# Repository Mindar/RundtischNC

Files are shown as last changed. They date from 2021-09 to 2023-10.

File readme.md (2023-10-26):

# Rundtisch NC
Rundtisch NC is a numerical control for indexing heads. It allows you to set a number of divisons using a rotary encoder and then drives the right distance on the push of a button.

*For international visitors: Unfortunately this repository is mostly in german. A notable exception to this is the firmware. In the future there might be a english version of the documentation, but for now there isn't one 😪*

[User manual / Bedienungsanleitung 🇩🇪 (.pdf)](./doc/bedienungsanleitung.pdf)

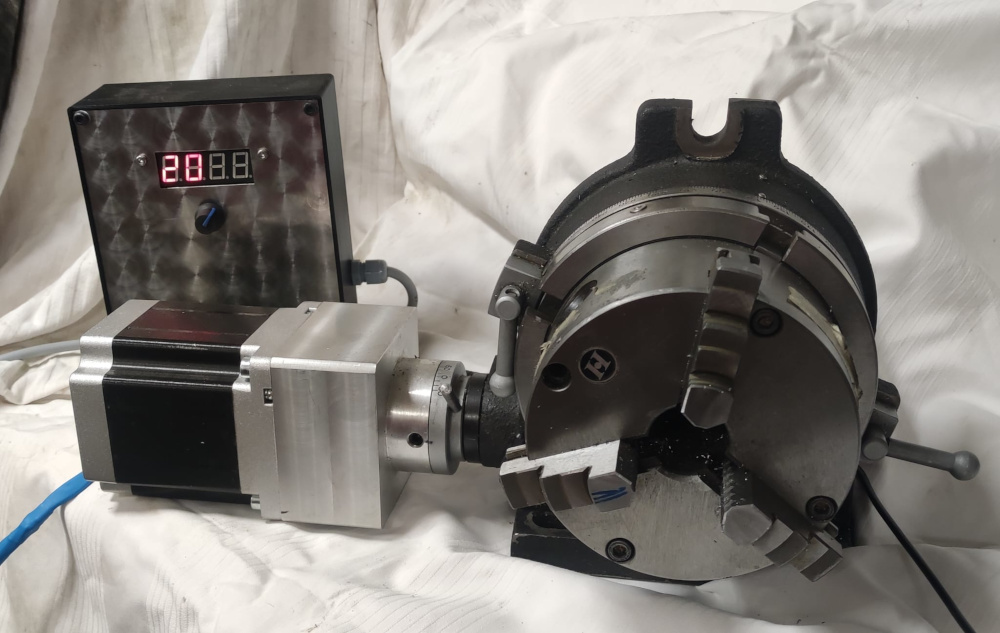
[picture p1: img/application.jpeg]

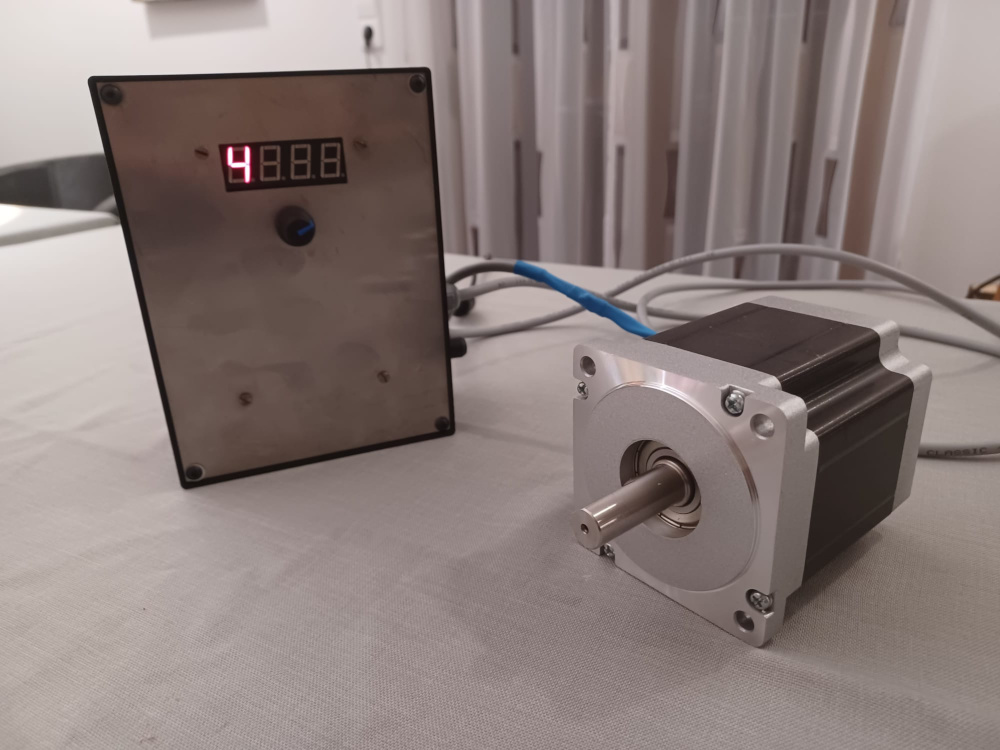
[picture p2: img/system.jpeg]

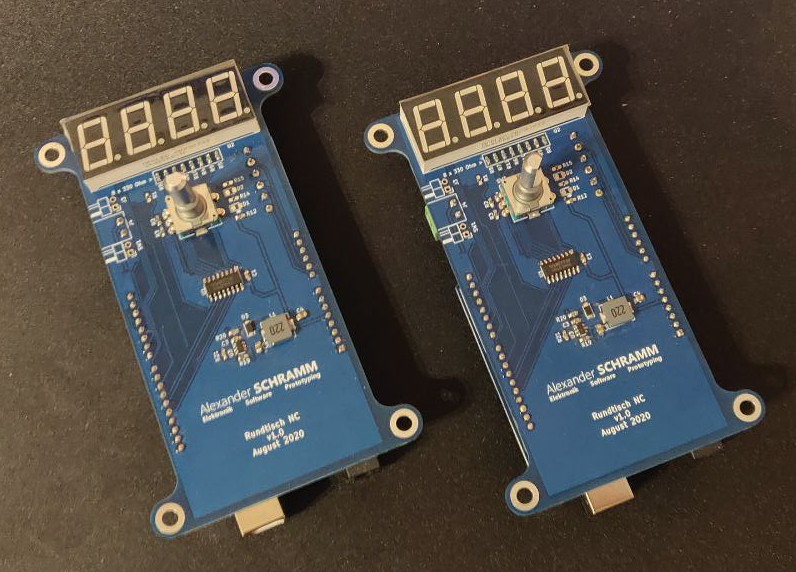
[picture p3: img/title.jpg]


## License
- Firmware: MIT
- Documentation, PCB layout, schematic, images: Creative Commons CC-BY (or MIT)

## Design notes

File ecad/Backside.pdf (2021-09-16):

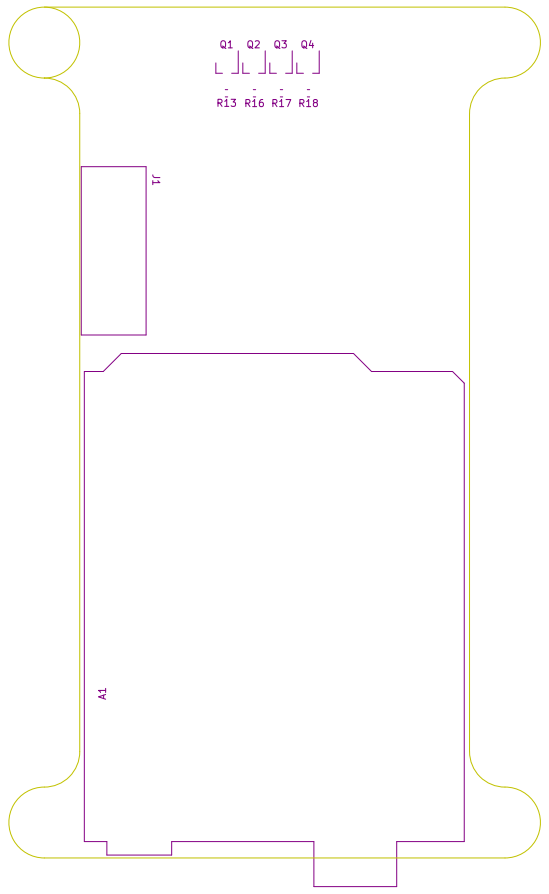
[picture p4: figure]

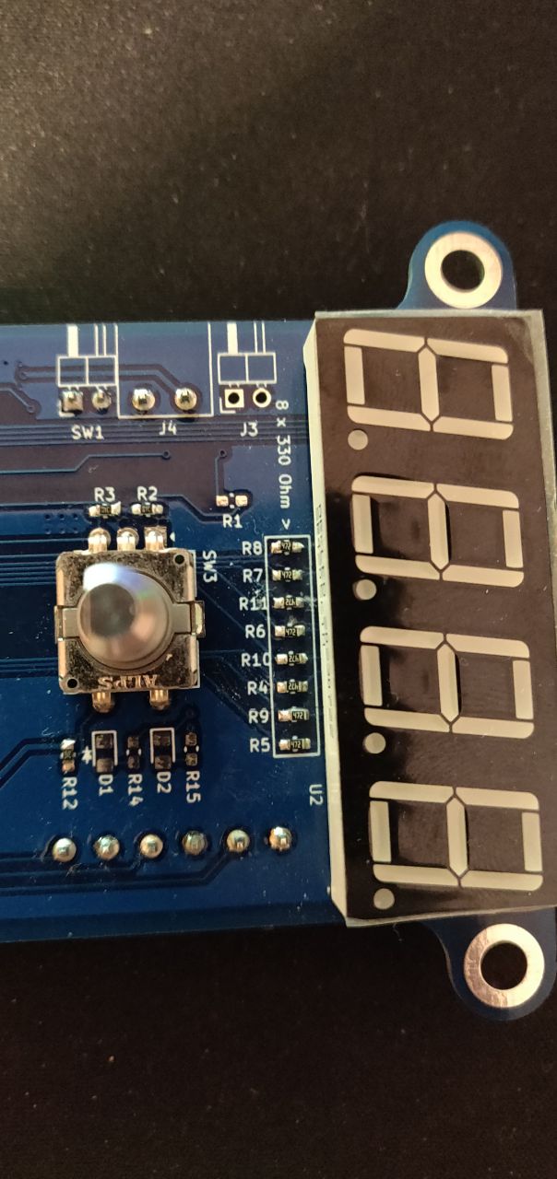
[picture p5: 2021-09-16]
img/display-widerstände.jpg

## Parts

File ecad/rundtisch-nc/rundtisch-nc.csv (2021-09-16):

Source: | /home/alex/Dokumente/firma/produkte/rundtisch-nc/ecad/rundtisch-nc/rundtisch-nc.kicad_sch
Date: | Sa 03 Okt 2020 22:12:33 CEST
Tool: | Eeschema (5.99.0-3702-g8080647d3-dirty)
Generator: | /usr/local/share/kicad/plugins/bom_csv_grouped_by_value_with_fp.py
Component Count: | 44
Ref | Qnty | Value | Cmp name | Footprint | Description | Vendor
A1, | 1 | Arduino_UNO_R3 | Arduino_UNO_R3 | Module:Arduino_UNO_R3 | Arduino UNO Microcontroller Module, release 3
C1, C3, | 2 | 100nF | C | Capacitor_SMD:C_0603_1608Metric_Pad1.05x0.95mm_HandSolder | Unpolarized capacitor
C2, C4, | 2 | 10uF | C | Capacitor_SMD:C_0805_2012Metric_Pad1.15x1.40mm_HandSolder | Unpolarized capacitor
D1, | 1 | Mode 1 LED | LED | LED_SMD:LED_0805_2012Metric_Pad1.15x1.40mm_HandSolder | Light emitting diode
D2, | 1 | Mode 2 LED | LED | LED_SMD:LED_0805_2012Metric_Pad1.15x1.40mm_HandSolder | Light emitting diode
D3, | 1 | DSK14 | D_Schottky | Diode_SMD:D_SOD-123 | Schottky diode
J1, | 1 | Motor Connector | Conn_01x06 | sonstige:WJ15EDGRC-3.81-6P | Generic connector, single row, 01x06, script generated (kicad-library-utils/schlib/autogen/connector/)
J2, | 1 | Conn_01x02_Male | Conn_01x02_Male |  | Generic connector, single row, 01x02, script generated (kicad-library-utils/schlib/autogen/connector/)
J3, | 1 | Feed Button Connector | Conn_01x02_Female | Connector_PinHeader_2.54mm:PinHeader_1x02_P2.54mm_Horizontal | Generic connector, single row, 01x02, script generated (kicad-library-utils/schlib/autogen/connector/)
J4, | 1 | Power In | Conn_01x02 | sonstige:WJ15EDGRC-3.81-2P | Generic connector, single row, 01x02, script generated (kicad-library-utils/schlib/autogen/connector/)
L1, | 1 | FXC0630-220M | L | sonstige:FXC0630-220M | Inductor
Q1, Q2, Q3, Q4, | 4 | AO3402 | Q_NMOS_GDS | Package_TO_SOT_SMD:SOT-23_Handsoldering | N-MOSFET transistor, gate/drain/source
R1, R2, R3, R12, R13, R16, R17, R18, R19, | 9 | 10K | R | Resistor_SMD:R_0603_1608Metric_Pad1.05x0.95mm_HandSolder | Resistor
R4, R5, R6, R7, R8, R9, R10, R11, | 8 | 330R | R | Resistor_SMD:R_0603_1608Metric_Pad1.05x0.95mm_HandSolder | Resistor
R14, R15, | 2 | 470R | R | Resistor_SMD:R_0603_1608Metric_Pad1.05x0.95mm_HandSolder | Resistor
R20, | 1 | 50K | R | Resistor_SMD:R_0603_1608Metric_Pad1.05x0.95mm_HandSolder | Resistor
R21, | 1 | 9.53K | R | Resistor_SMD:R_0603_1608Metric_Pad1.05x0.95mm_HandSolder | Resistor
SW1, | 1 | Reset Button | SW_Push | Connector_PinHeader_2.54mm:PinHeader_1x02_P2.54mm_Horizontal | Push button switch, generic, two pins
SW2, | 1 | Feed Advance Button | SW_Push |  | Push button switch, generic, two pins
SW3, | 1 | Rotary Encoder | Rotary_Encoder_Switch | Rotary_Encoder:RotaryEncoder_Alps_EC11E-Switch_Vertical_H20mm | Rotary encoder, dual channel, incremental quadrate outputs, with switch
U1, | 1 | 74HC595 | 74HC595 | Package_SO:SOIC-16_3.9x9.9mm_P1.27mm | 8-bit serial in/out Shift Register 3-State Outputs
U2, | 1 | SR420561N | CC56-12YWA | sonstige:SR420561N | 4 digit 7 segment yellow LED, common cathode
U3, | 1 | AOZ1282CI | AOZ1282CI | Package_TO_SOT_SMD:SOT-23-6 | 1.2 A Simple Buck Regulator, 4.5-36V input, 450kHz

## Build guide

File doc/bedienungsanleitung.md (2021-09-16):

# Bedienungsanleitung

## Verkabelung
Es müssen nur die beiden grünen Steckverbinder verkabelt werden. An den 6-poligen Steckverbinder wird der Motortreiber angeschlossen. An den 2-poligen Steckverbinder wird die Stromversorgung angeschlossen.

### Motortreiber
Der Schrittmotortreiber muss auf 400 Schritte pro Umdrehung eingestellt werden. Falls das nicht möglich ist, oder eine andere Schritteinstellung verwendet werden soll, siehe unten Abschnitt im "Firmware Einstellungen".

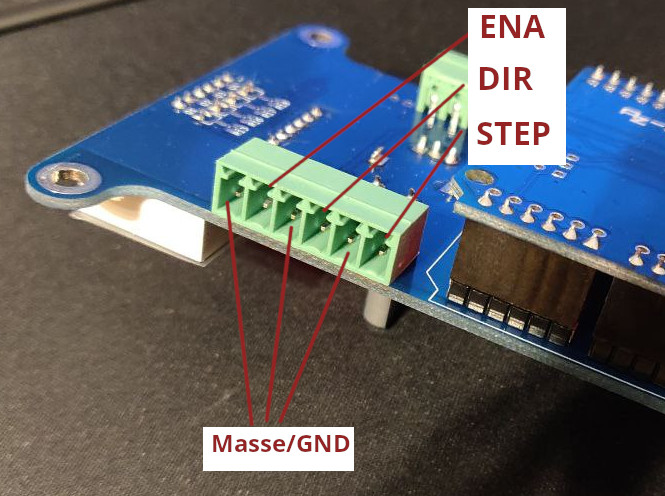
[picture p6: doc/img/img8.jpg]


Pin 1 des 6-poligen Steckverbinders J1 ist näher am Arduino, Pin 6 ist neben dem Schriftzug "J1". Die Pins müssen wie folgt verkabelt werden:

<table>
<thead>
	<tr>
		<th>Pin</th>
		<th>Bezeichnung</th>
		<th>Zugehöriger Pin am Motortreiber</th>
	</tr>
</thead>
<tbody>
	<tr>
		<td>J1.1</td>
		<td>STEP</td>
		<td>Schrittimpulseingang (meistens mit PUL, PULSE, STEP oder STP beschriftet)</td>
	</tr>
	<tr>
		<td>J1.2</td>
		<td>GND</td>
		<td>Masse für Schrittimpulseingang (meistens auch mit STEP- oder GND beschriftet)</td>
	</tr>
	<tr>
		<td>J1.3</td>
		<td>DIR</td>
		<td>Richtungseingang (meistens mit DIR oder DIR+ beschriftet)</td>
	</tr>
	<tr>
		<td>J1.4</td>
		<td>GND</td>
		<td>Masse für Richtungseingang (meistens mit DIR- oder GND beschriftet)</td>
	</tr>
	<tr>
		<td>J1.5</td>
		<td>STEP</td>
		<td>Enable-Eingang (meistens auch mit ENA oder ENA+ beschriftet)</td>
	</tr>
	<tr>
		<td>J1.6</td>
		<td>GND</td>
		<td>Masse für Enable (meistens mit ENA- oder GND beschriftet)</td>
	</tr>
</tbody>
</table>

### Versorgungsspannung
Am 2-poligen Steckverbinder J4 wird die Versorgungsspannung angeschlossen. Die Versorgungsspannung darf maximal 24V (Gleichspannung) betragen. Getestet wird mit 12V.

Die Pins von J4 (Achtung: Beschriftung ist auf gegenüberliegender Seite) sind gleich nummeriert wie die von J1, d.h. "unten" (also näher am Arduino) ist Pin 1.

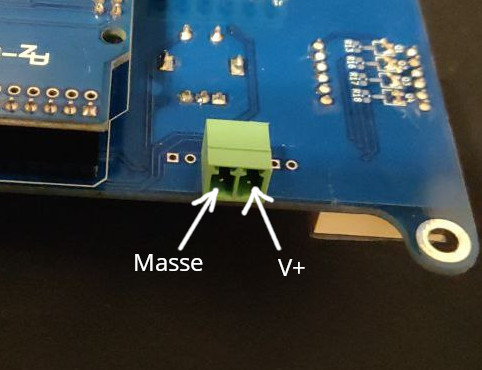
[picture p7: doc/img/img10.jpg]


<table>
<thead>
	<tr>
		<th>Pin</th>
		<th>Bezeichnung</th>
	</tr>
</thead>
<tbody>
	<tr>
		<td>J4.1</td>
		<td>GND</td>
	</tr>
	<tr>
		<td>J4.2</td>
		<td>V+ (kann zwischen )</td>
	</tr>
</tbody>
</table>

## Bedienung

Nach dem Einschalten zeigt das Board den Begrüßungstext "HELO" an.

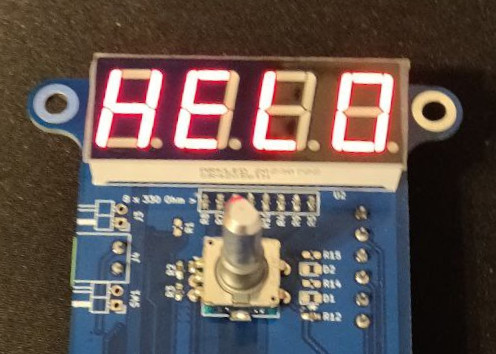
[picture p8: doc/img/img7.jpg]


Danach wird die Zahl der derzeit ausgewählten Schritte Pro Umdrehung angezeigt. Der Standardwert ist 1. Durch drehen des Drehencoders kann die Anzahl frei zwischen 1 - 9999 eingestellt werden. Im folgenden Bild wurde die Zahl auf den Wert 9 eingestellt. Pro Schritt wird also eine 9tel Umdrehung des Teilapparats bzw. 40° gefahren.

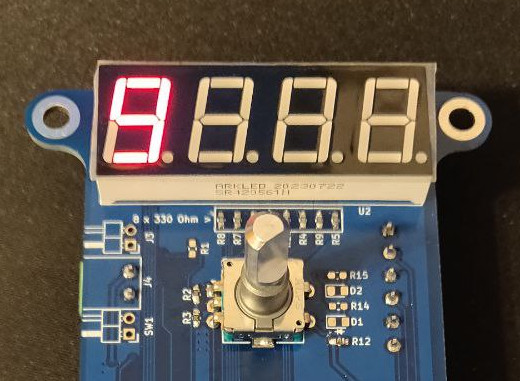
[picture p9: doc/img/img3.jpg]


Durch drücken des Drehencoders wird die Zahl für die weiteren Schritte fest eingestellt. Der Text "Loc" erscheint.

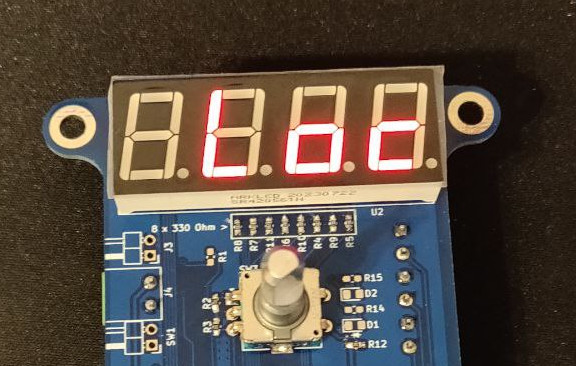
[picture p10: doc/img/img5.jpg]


Danach erscheint wieder die eingestellte Teil-Zahl. Das Gerät ist nun "scharf": Wenn der Drehencoder nun ein weiteres mal gedrückt wird, fährt der Teilapparat die eingestellte Strecke.

## Sonstiges

### Firmware Einstellungen
Die Software geht davon aus, dass der Schrittmotortreiber auf 400 Schritte pro Umdrehung eingestellt ist, und der Teilapparat sich bei 90 Umdrehungen der Eingangswelle um 360° dreht. Sollte das nicht der Fall sein, muss die Firmware angepasst werden.
Das geschieht mit der Software "Visual Studio Code" von Microsoft mit der Extension "PlatformIO". Die Firmware kann von https://github.com/Mindar/RundtischNC heruntergeladen werden.

In der Datei ```./include/config.hpp``` befinden sich alle Konfigurationsoptionen, die eingestellt werden können. Hier eine kurze Erkärung der Optionen:

<table>
<thead>
	<tr>
		<th>Bezeichnung</th>
		<th>Standardwert</th>
		<th>Beschreibung</th>
	</tr>
</thead>
<tbody>
	<tr>
		<td>INDEXING_HEAD_GEAR_RATIO</td>
		<td>90L</td>
		<td>Das Untersetzungsverhältnis des Teilapparats. Für eine Umdrehung des Ausgangs sind so viele Motorumdrehungen nötig.</td>
	</tr>
	<tr>
		<td>STEPS_PER_REV</td>
		<td>400L</td>
		<td>Anzahl der Schritte die der Motortreiber und Motor für eine Motorumdrehung benötigt. Wenn am Motortreiber die Microstep Einstellung geändert wird, muss dieser Wert ebenfalls geändert werden.</td>
	</tr>
	<tr>
		<td>MAX_SPEED</td>
		<td>90 * 5</td>
		<td>Die maximale Geschwindigkeit des Motors in Umdrehungen pro Minute. Bei zu hohen Werten verliert der Motor Schritte, bzw. der Arduino kann nicht schnell genug die Schritte schicken. In letzterem Fall wird die eingestellte Geschwindigkeit nicht erreicht.</td>
	</tr>
	<tr>
		<td>MAX_ACCEL</td>
		<td>90</td>
		<td>Die maximale Drehbeschleunigung des Motors, d.h. wie schnell der Motor "auf Touren" kommt. Bei zu hohen Werten verliert der Motor Schritte.</td>
	</tr>
</tbody>
</table>

Nachdem die Einstellungen wie gewünscht eingestellt wurden, muss der Code hochgeladen werden. Hierfür muss die Platine ausschließlich mit einem USB Kabel an den PC angeschlossen werden. In Visual Studio Code muss man die Taste F1 drücken und dann "PlatformIO Upload" eingeben und mit der Enter Taste bestätigen. Nach dem Upload erscheint im Terminal bei Erfolg die Meldung "======== \[SUCCESS\] Took 1.23 seconds ========"

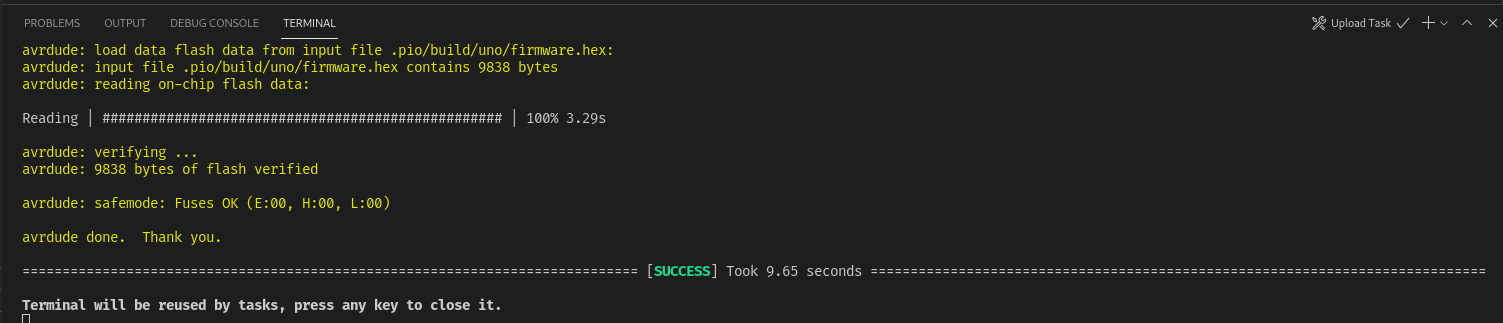
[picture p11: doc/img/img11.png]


## Lizenz
Die Firmware steht unter der MIT Lizenz. Der Rest (d.h. Doku, Schaltplan, PCB Layout, Fotos) steht unter CC-BY Lizenz.

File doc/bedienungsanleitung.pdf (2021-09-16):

# Bedienungsanleitung

## Verkabelung

Es müssen nur die beiden grünen Steckverbinder verkabelt werden. An den 6-poligen Steckverbinder wird der Motortreiber angeschlossen. An den 2-poligen Steckverbinder wird die Stromversorgung angeschlossen.
Motortreiber

Der Schrittmotortreiber muss auf 400 Schritte pro Umdrehung eingestellt werden. Falls das nicht möglich ist, oder eine andere Schritteinstellung verwendet werden soll, siehe unten Abschnitt im "Firmware Einstellungen".


Pin 1 des 6-poligen Steckverbinders J1 ist näher am Arduino, Pin 6 ist neben dem Schriftzug "J1". Die Pins müssen wie folgt verkabelt werden:

Pin | Bezeichnung Zugehöriger Pin am Motortreiber
J1.1 STEP | Schrittimpulseingang (meistens mit PUL, PULSE, STEP oder STP beschriftet)
J1.2 GND | Masse für Schrittimpulseingang (meistens auch mit STEP- oder GND beschriftet)
J1.3 DIR | Richtungseingang (meistens mit DIR oder DIR+ beschriftet)
J1.4 GND | Masse für Richtungseingang (meistens mit DIR- oder GND beschriftet)

Pin | Bezeichnung Zugehöriger Pin am Motortreiber
J1.5 STEP | Enable-Eingang (meistens auch mit ENA oder ENA+ beschriftet)
J1.6 GND | Masse für Enable (meistens mit ENA- oder GND beschriftet)

Versorgungsspannung

Am 2-poligen Steckverbinder J4 wird die Versorgungsspannung angeschlossen. Die Versorgungsspannung darf maximal 24V (Gleichspannung) betragen. Getestet wird mit 12V.

Die Pins von J4 (Achtung: Beschriftung ist auf gegenüberliegender Seite) sind gleich nummeriert wie die von J1, d.h. "unten" (also näher am Arduino) ist Pin 1.


Pin Bezeichnung

J4.1 GND

J4.2 V+ (kann zwischen )

## Bedienung

Nach dem Einschalten zeigt das Board den Begrüßungstext "HELO" an.

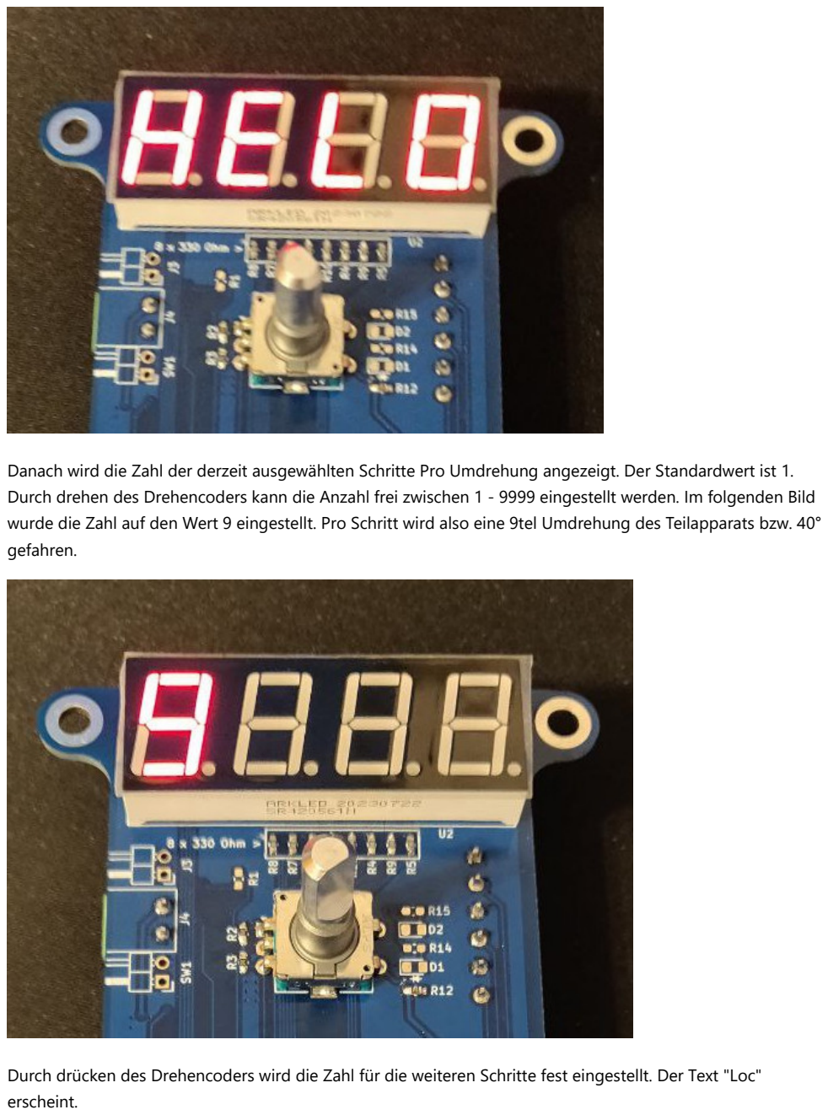
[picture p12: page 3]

Danach wird die Zahl der derzeit ausgewählten Schritte Pro Umdrehung angezeigt. Der Standardwert ist 1. Durch drehen des Drehencoders kann die Anzahl frei zwischen 1 - 9999 eingestellt werden. Im folgenden Bild wurde die Zahl auf den Wert 9 eingestellt. Pro Schritt wird also eine 9tel Umdrehung des Teilapparats bzw. 40° gefahren.

Durch drücken des Drehencoders wird die Zahl für die weiteren Schritte fest eingestellt. Der Text "Loc" erscheint.


Danach erscheint wieder die eingestellte Teil-Zahl. Das Gerät ist nun "scharf": Wenn der Drehencoder nun ein weiteres mal gedrückt wird, fährt der Teilapparat die eingestellte Strecke.

## Sonstiges

Firmware Einstellungen

Die Software geht davon aus, dass der Schrittmotortreiber auf 400 Schritte pro Umdrehung eingestellt ist, und der Teilapparat sich bei 90 Umdrehungen der Eingangswelle um 360° dreht. Sollte das nicht der Fall sein, muss die Firmware angepasst werden. Das geschieht mit der Software "Visual Studio Code" von Microsoft mit der Extension "PlatformIO". Die Firmware kann von https://github.com/Mindar/RundtischNC heruntergeladen werden.

In der Datei ./include/config.hpp befinden sich alle Konfigurationsoptionen, die eingestellt werden können. Hier eine kurze Erkärung der Optionen:

Bezeichnung | Standardwert Beschreibung

INDEXING_HEAD_GEAR_RATIO 90L

| Das Untersetzungsverhältnis des Teilapparats. Für eine Umdrehung des Ausgangs sind so viele Motorumdrehungen nötig.
STEPS_PER_REV | 400L

Anzahl der Schritte die der Motortreiber und Motor für eine Motorumdrehung benötigt. Wenn am Motortreiber die Microstep Einstellung geändert wird, muss dieser Wert ebenfalls geändert werden.

Bezeichnung | Standardwert Beschreibung
MAX_SPEED | 90 * 5

Die maximale Geschwindigkeit des Motors in Umdrehungen pro Minute. Bei zu hohen Werten verliert der Motor Schritte, bzw. der Arduino kann nicht schnell genug die Schritte schicken. In letzterem Fall wird die eingestellte Geschwindigkeit nicht erreicht.

MAX_ACCEL | 90

Die maximale Drehbeschleunigung des Motors, d.h. wie schnell der Motor "auf Touren" kommt. Bei zu hohen Werten verliert der Motor Schritte.

Nachdem die Einstellungen wie gewünscht eingestellt wurden, muss der Code hochgeladen werden. Hierfür muss die Platine ausschließlich mit einem USB Kabel an den PC angeschlossen werden. In Visual Studio Code muss man die Taste F1 drücken und dann "PlatformIO Upload" eingeben und mit der Enter Taste bestätigen. Nach dem Upload erscheint im Terminal bei Erfolg die Meldung "======== [SUCCESS] Took 1.23 seconds ========"

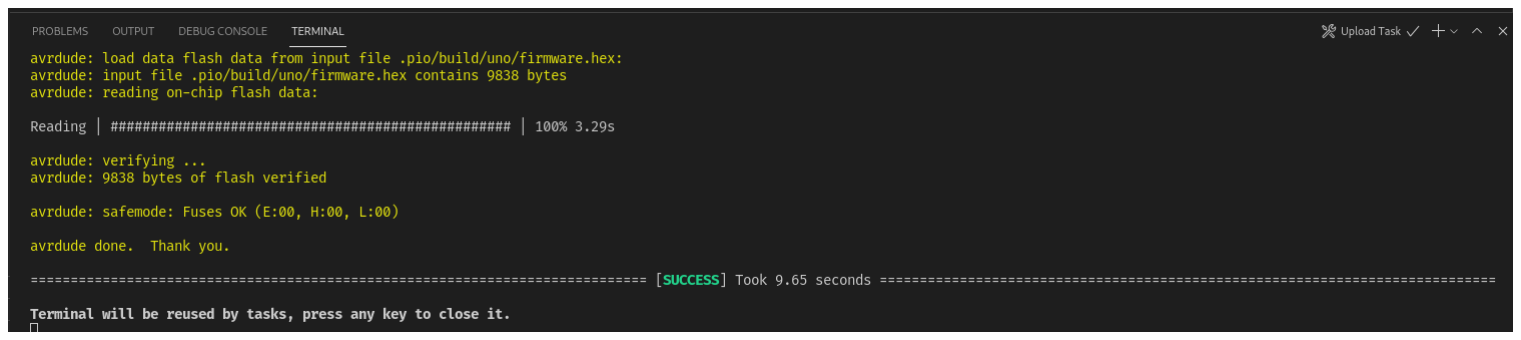
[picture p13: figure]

## Lizenz

Die Firmware steht unter der MIT Lizenz. Der Rest (d.h. Doku, Schaltplan, PCB Layout, Fotos) steht unter CC-BY Lizenz.

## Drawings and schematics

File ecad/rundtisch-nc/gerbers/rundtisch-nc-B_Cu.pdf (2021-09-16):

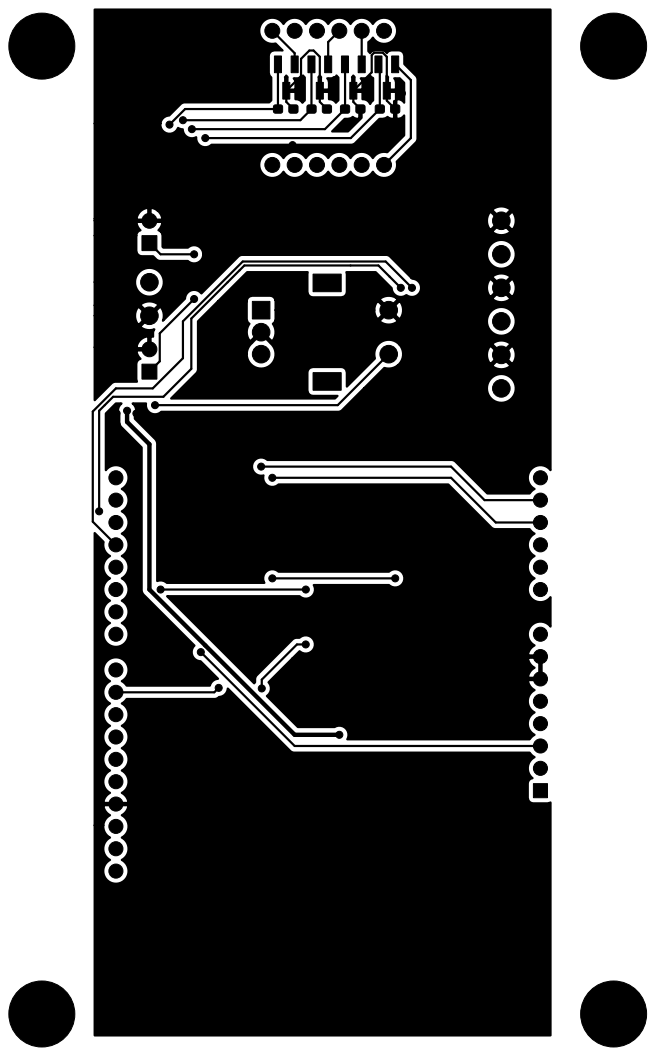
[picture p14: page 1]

File: rundtisch-nc.kicad_pcb Sheet:
Id: 1/1 Title:

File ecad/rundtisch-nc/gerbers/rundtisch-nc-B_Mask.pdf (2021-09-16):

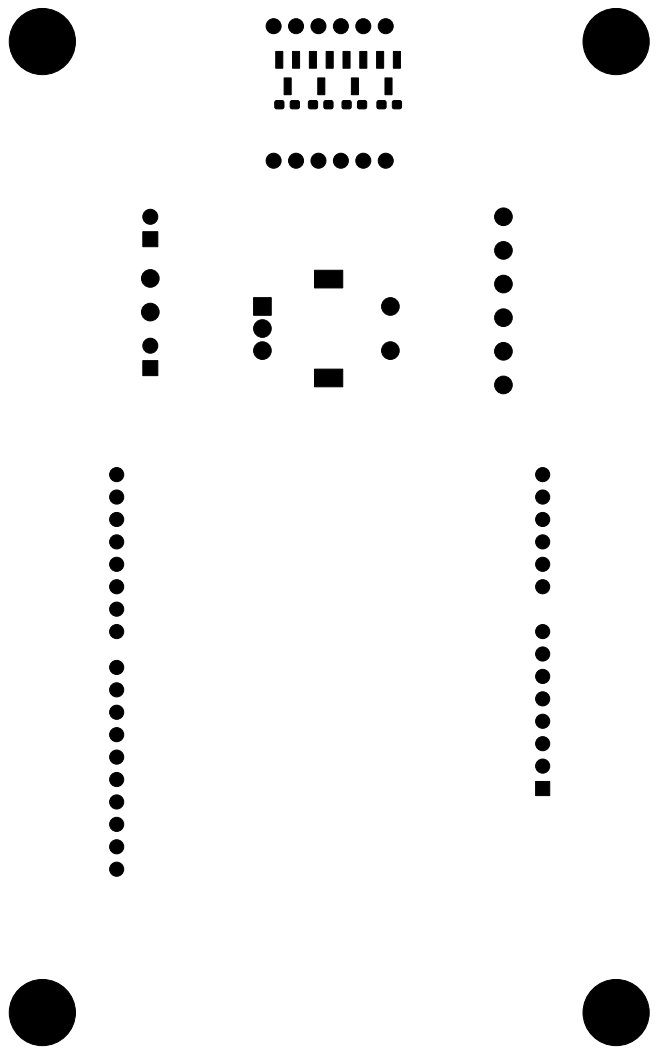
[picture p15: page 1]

File: rundtisch-nc.kicad_pcb Sheet:
Id: 1/1 Title:

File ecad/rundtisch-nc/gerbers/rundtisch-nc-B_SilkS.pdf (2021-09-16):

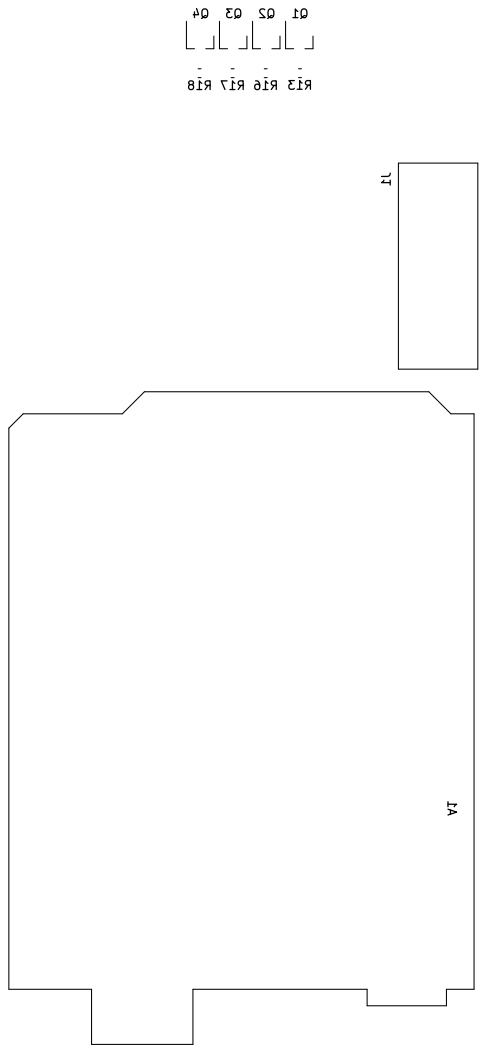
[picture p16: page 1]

File: rundtisch-nc.kicad_pcb Sheet:
Id: 1/1 Title:

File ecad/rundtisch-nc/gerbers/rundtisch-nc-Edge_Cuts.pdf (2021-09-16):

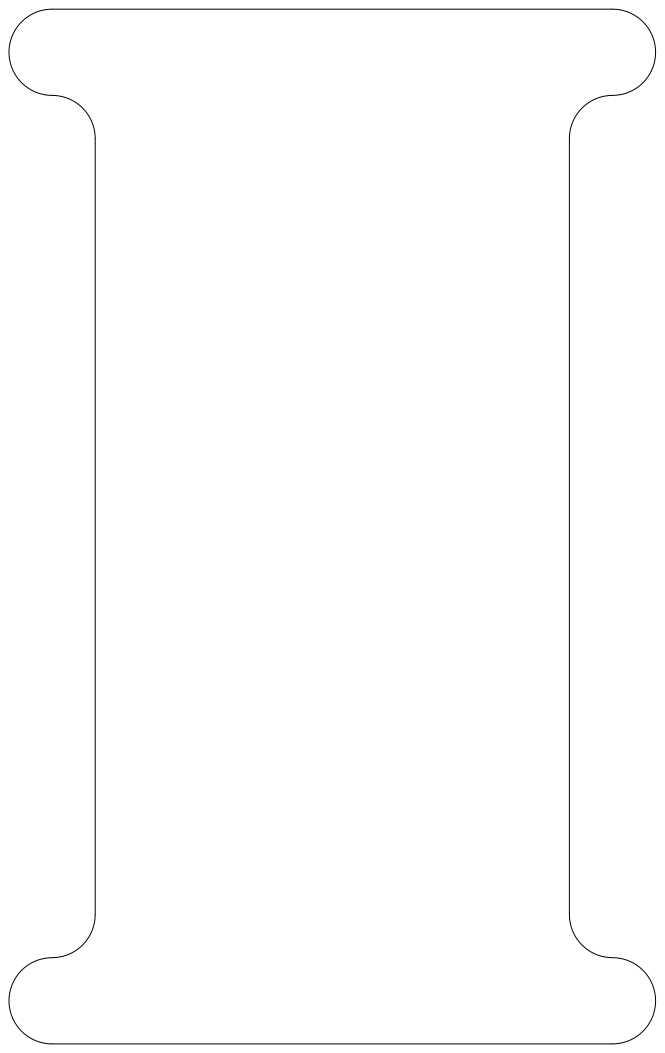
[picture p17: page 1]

File: rundtisch-nc.kicad_pcb Sheet:
Id: 1/1 Title:

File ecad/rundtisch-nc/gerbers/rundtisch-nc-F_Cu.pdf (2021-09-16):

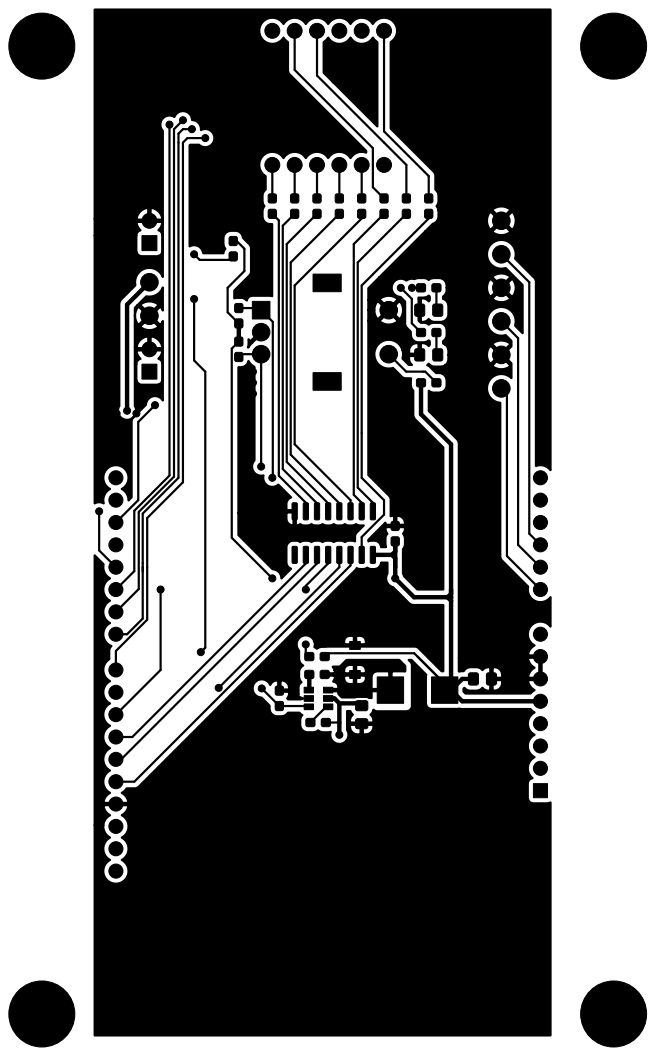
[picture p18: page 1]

File: rundtisch-nc.kicad_pcb Sheet:
Id: 1/1 Title:

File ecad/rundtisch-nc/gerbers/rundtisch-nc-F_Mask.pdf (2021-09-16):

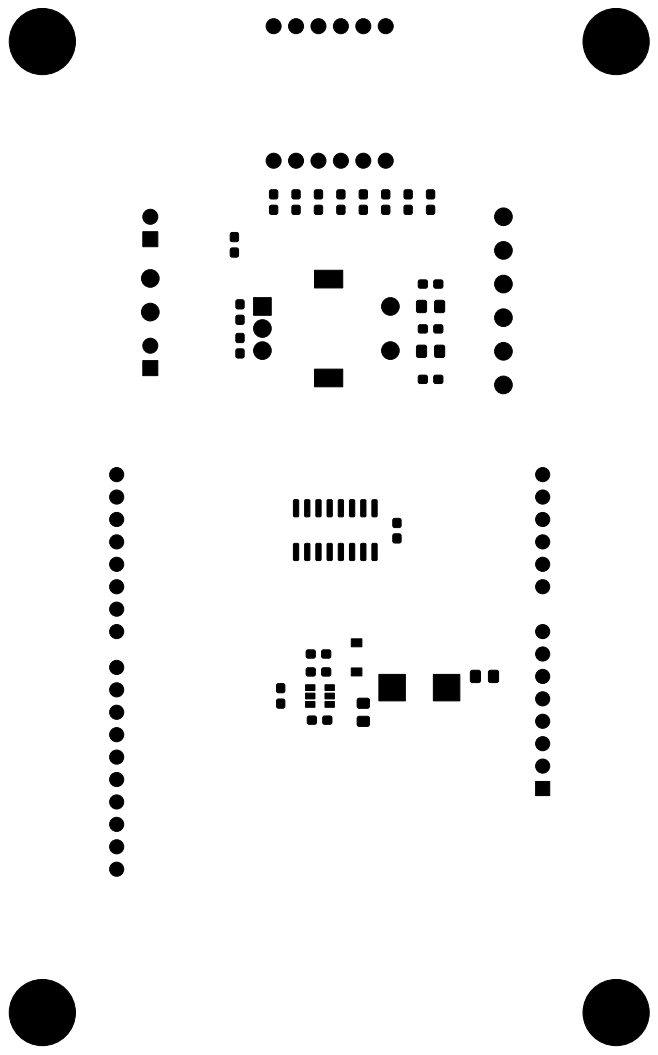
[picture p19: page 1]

File: rundtisch-nc.kicad_pcb Sheet:
Id: 1/1 Title:

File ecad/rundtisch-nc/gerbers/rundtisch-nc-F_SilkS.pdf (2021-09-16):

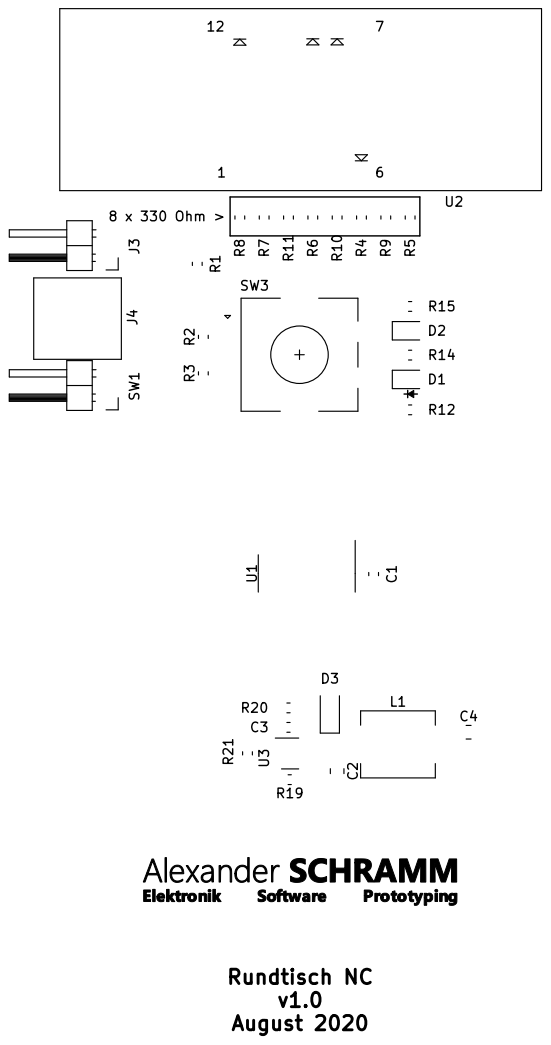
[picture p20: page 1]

File: rundtisch-nc.kicad_pcb Sheet: Rundtisch NC
v1.0 August 2020

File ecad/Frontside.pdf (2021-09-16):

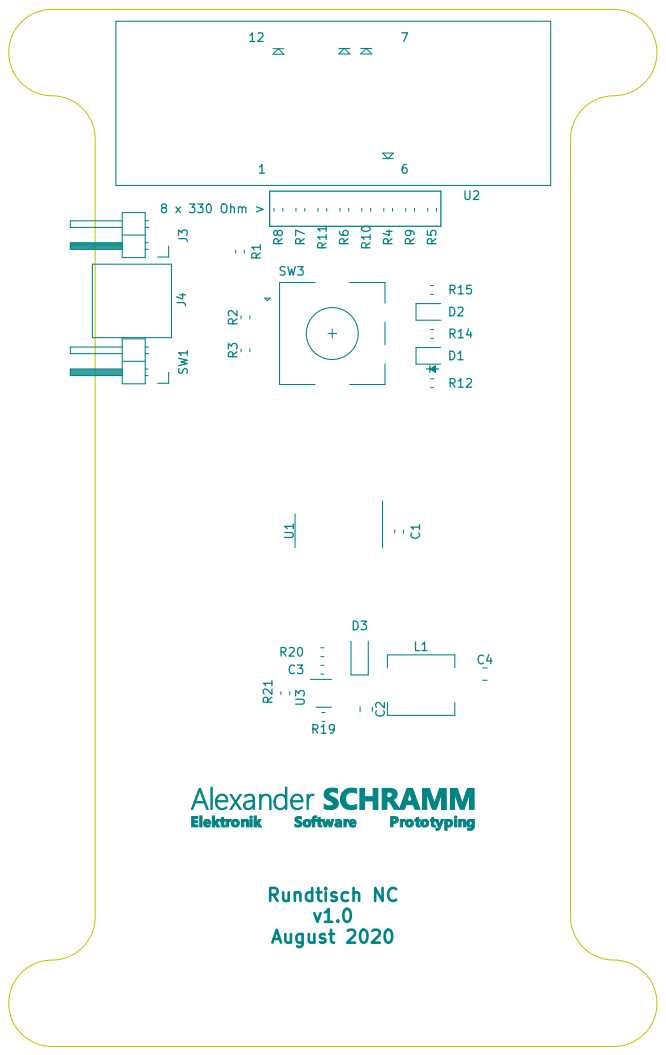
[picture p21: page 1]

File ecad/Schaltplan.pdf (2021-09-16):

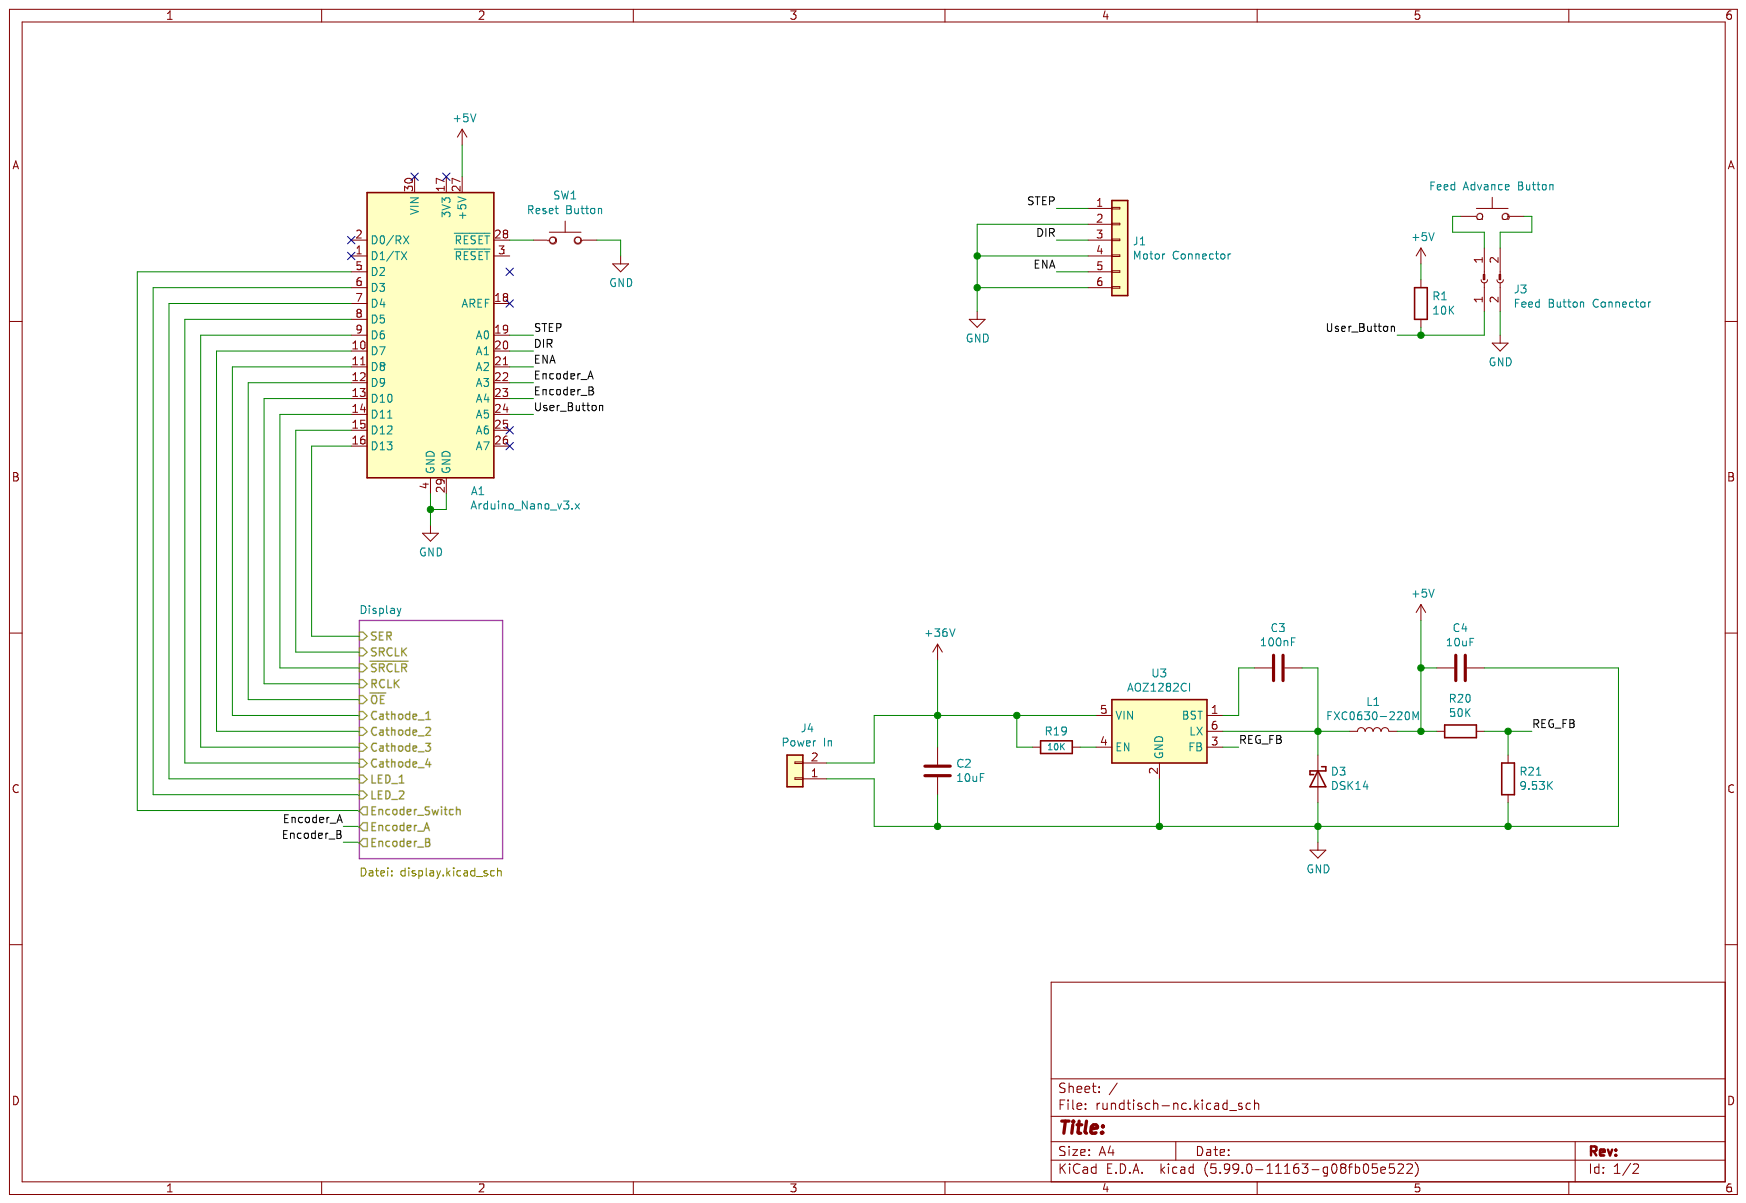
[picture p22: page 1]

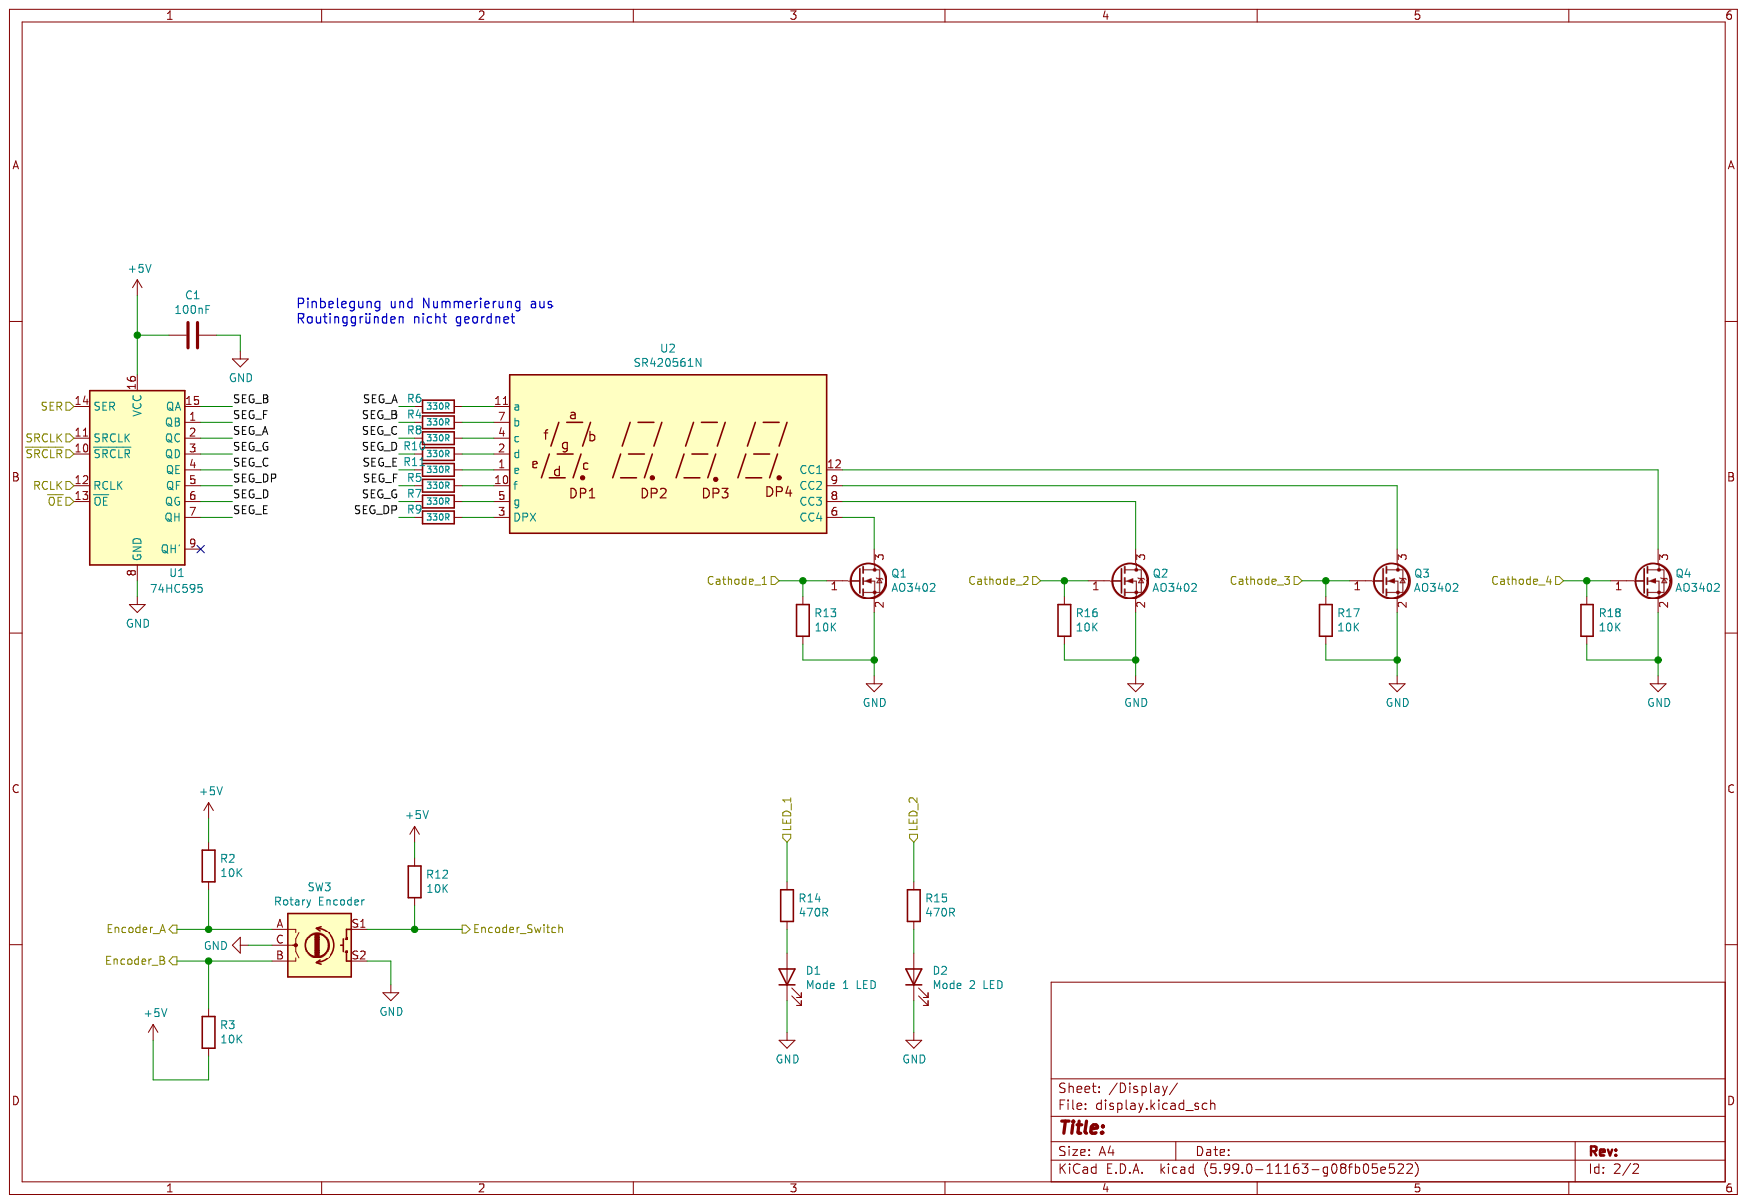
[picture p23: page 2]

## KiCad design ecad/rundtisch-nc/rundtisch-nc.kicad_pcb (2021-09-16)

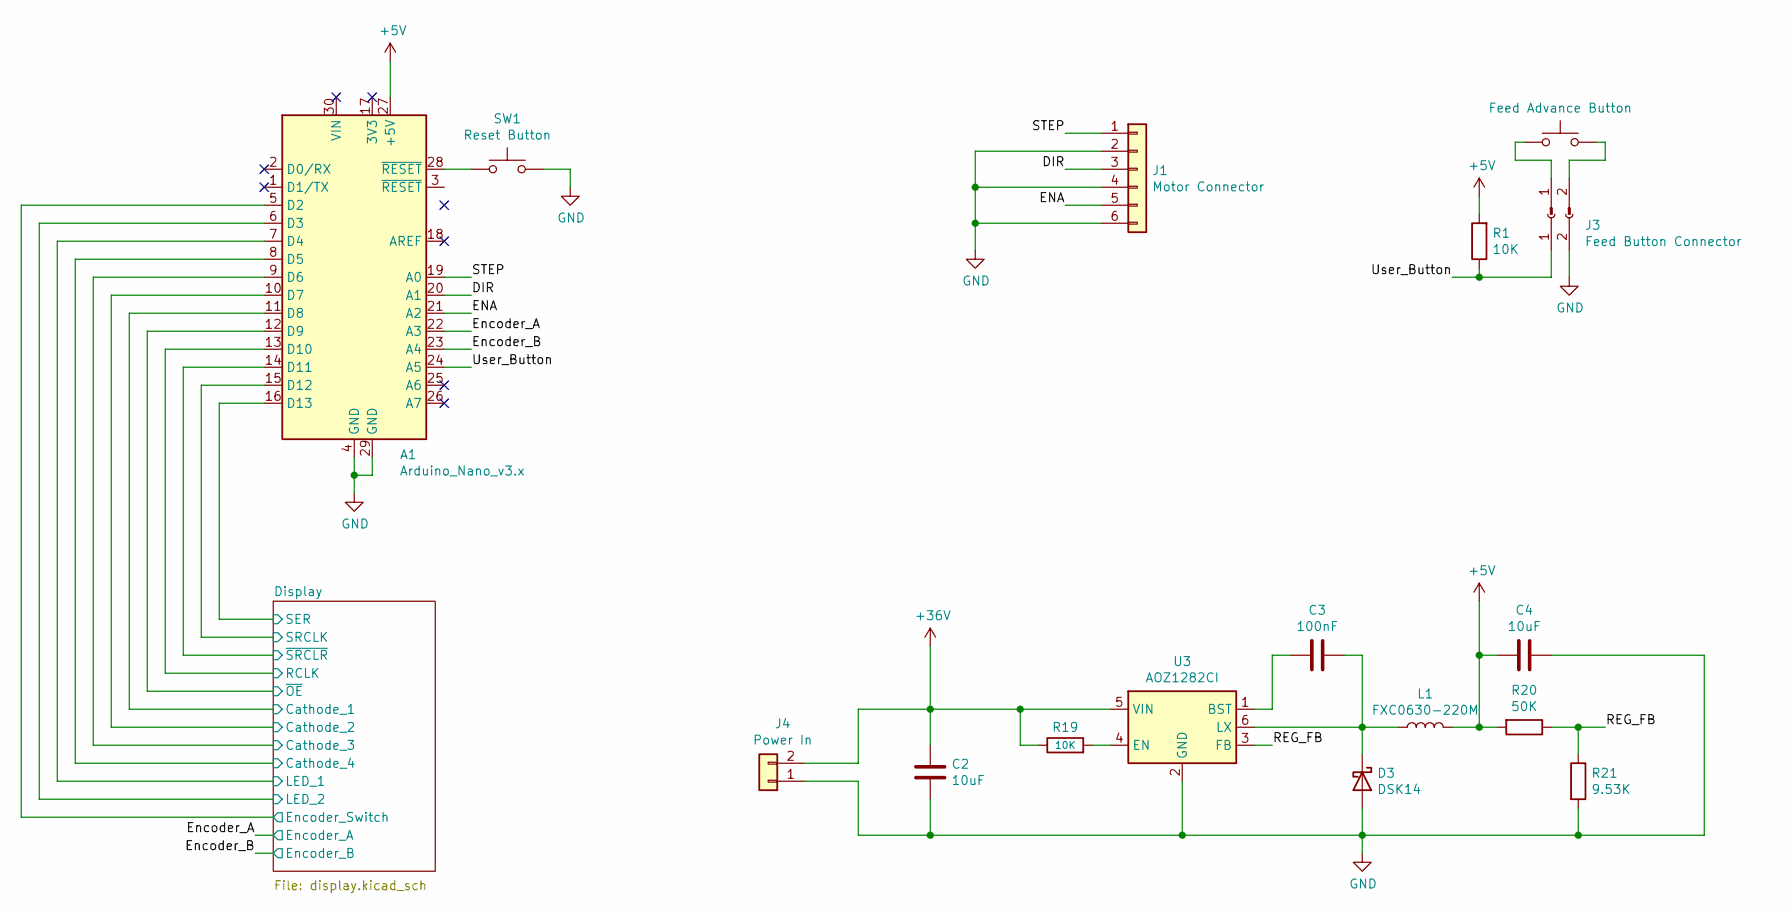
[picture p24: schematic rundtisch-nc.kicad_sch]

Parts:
A1: Arduino_Nano_v3.x; Arduino_Nano
C2, C4: 10uF; C_0805_2012Metric_Pad1.18x1.45mm_HandSolder
C3: 100nF; C_0603_1608Metric_Pad1.08x0.95mm_HandSolder
D3: DSK14; D_SOD-123
J1: Motor Connector; WJ15EDGRC-3.81-6P
J2: Feed Advance Stecker
J3: Feed Button Connector; WJ15EDGRC-3.81-2P
J4: Power In; WJ15EDGRC-3.81-2P
L1: FXC0630-220M
R1, R19: 10K; R_0603_1608Metric_Pad0.98x0.95mm_HandSolder
R20: 50K; R_0603_1608Metric_Pad0.98x0.95mm_HandSolder
R21: 9.53K; R_0603_1608Metric_Pad0.98x0.95mm_HandSolder
SW1: Reset Button; WJ15EDGRC-3.81-2P
SW2: Feed Advance Button; WJ15EDGRC-3.81-2P
U3: AOZ1282CI; SOT-23-6

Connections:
+5V: A1.27 (+5V), C4.1, L1.2, R1.2, R20.2; also elsewhere on the board
+36V: C2.1, J4.2, R19.1, U3.5 (VIN)
/DIR: A1.20 (A1), J1.3
/Display/Cathode_1: A1.11 (D8); also elsewhere on the board
/Display/Cathode_2: A1.10 (D7); also elsewhere on the board
/Display/Cathode_3: A1.9 (D6); also elsewhere on the board
/Display/Cathode_4: A1.8 (D5); also elsewhere on the board
/Display/Encoder_Switch: A1.5 (D2); also elsewhere on the board
/Display/LED_1: A1.7 (D4); also elsewhere on the board
/Display/LED_2: A1.6 (D3); also elsewhere on the board
/Display/RCLK: A1.13 (D10); also elsewhere on the board
/Display/SER: A1.16 (D13); also elsewhere on the board
/Display/SRCLK: A1.15 (D12); also elsewhere on the board
/Display/~OE: A1.12 (D9); also elsewhere on the board
/Display/~SRCLR: A1.14 (D11); also elsewhere on the board
/ENA: A1.21 (A2), J1.5
/Encoder_A: A1.22 (A3); also elsewhere on the board
/Encoder_B: A1.23 (A4); also elsewhere on the board
/REG_FB: R20.1, R21.1, U3.3 (FB)
/STEP: A1.19 (A0), J1.1
/User_Button: A1.24 (A5), J3.1, R1.1
GND: A1.4 (GND), A1.29 (GND), C2.2, C4.2, D3.2 (A), J1.2, J1.4, J1.6, J3.2, J4.1, R21.2, SW1.2, U3.2 (GND); also elsewhere on the board
unnamed: C3.1, U3.1 (BST)
unnamed: C3.2, D3.1 (K), L1.1, U3.6 (LX)
unnamed: J2.1, SW2.1
unnamed: J2.2, SW2.2
unnamed: R19.2, U3.4 (EN)
unnamed: A1.28 (~RESET), SW1.1

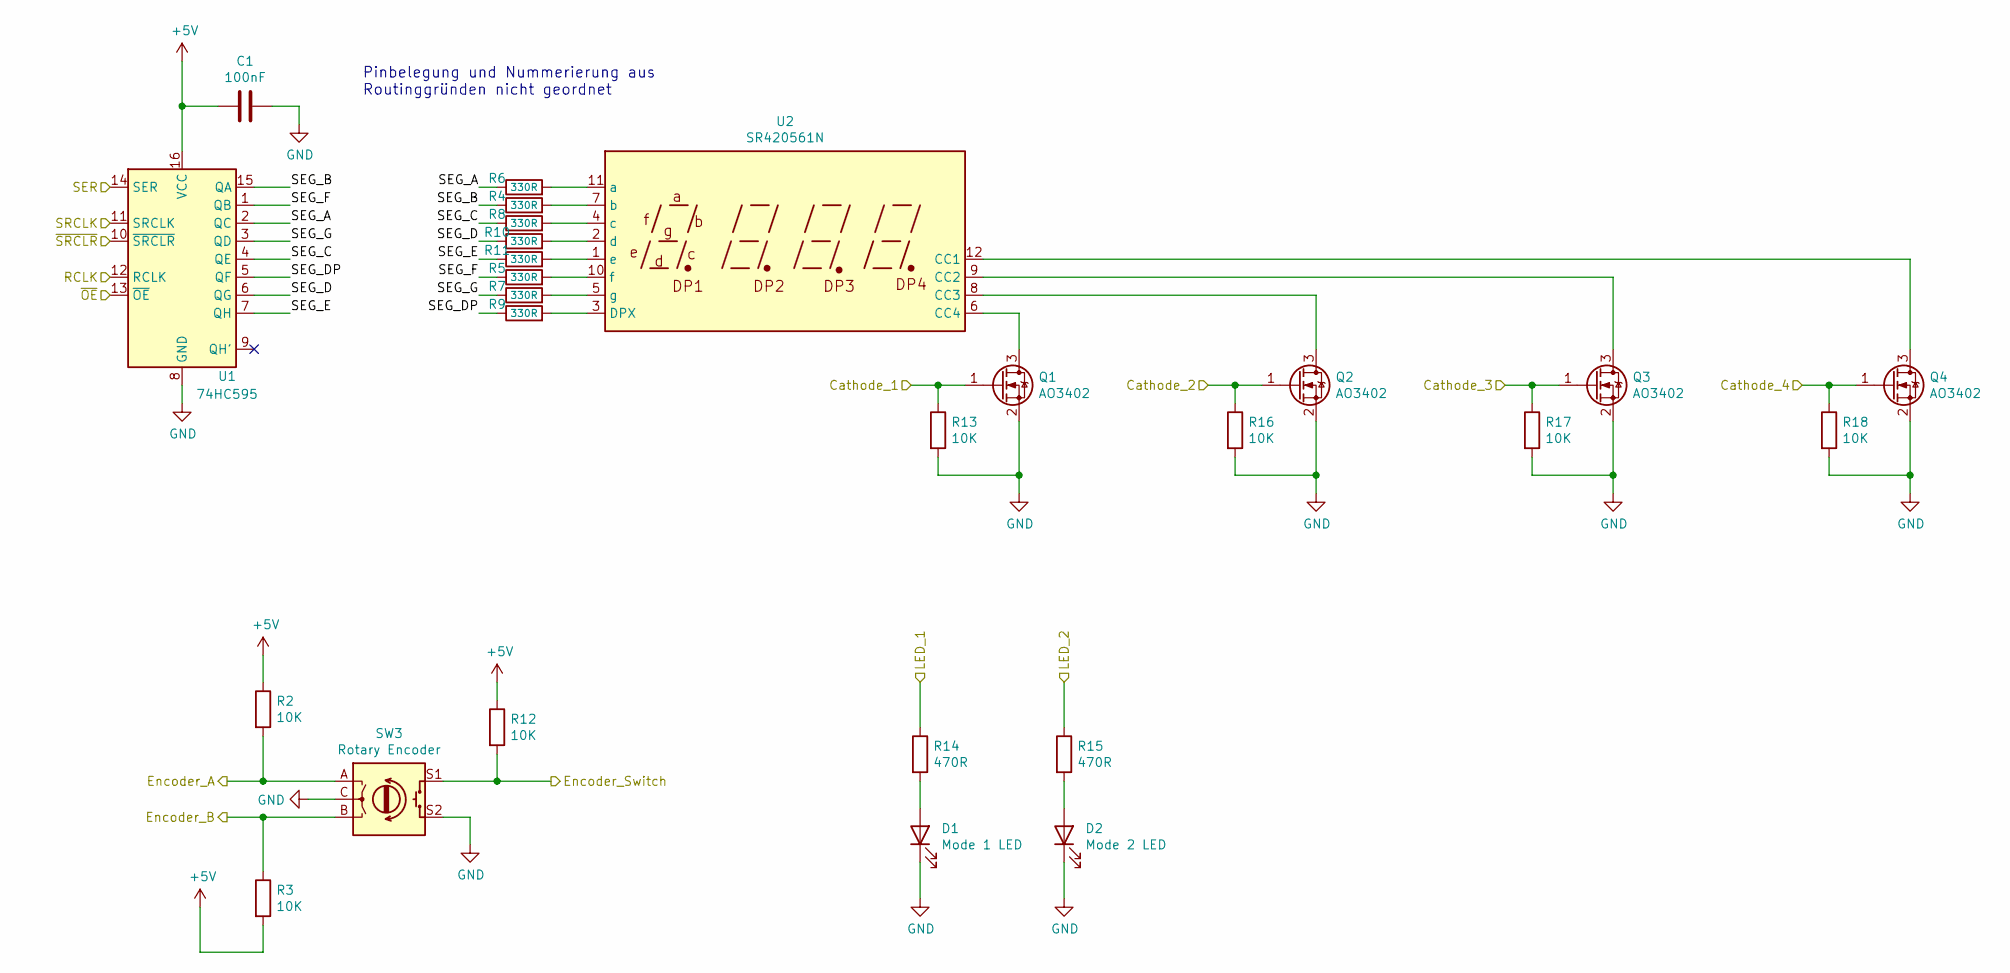
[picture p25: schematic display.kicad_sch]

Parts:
C1: 100nF; C_0603_1608Metric_Pad1.08x0.95mm_HandSolder
D1: Mode 1 LED; LED_0805_2012Metric_Pad1.15x1.40mm_HandSolder
D2: Mode 2 LED; LED_0805_2012Metric_Pad1.15x1.40mm_HandSolder
Q1, Q2, Q3, Q4: AO3402; SOT-23_Handsoldering
R2, R3, R12, R13, R16, R17, R18: 10K; R_0603_1608Metric_Pad0.98x0.95mm_HandSolder
R4, R5, R6, R7, R8, R9, R10, R11: 330R; R_0603_1608Metric_Pad0.98x0.95mm_HandSolder
R14, R15: 470R; R_0603_1608Metric_Pad0.98x0.95mm_HandSolder
SW3: Rotary Encoder; RotaryEncoder_Alps_EC11E-Switch_Vertical_H20mm
U1: 74HC595; SOIC-16_3.9x9.9mm_P1.27mm
U2: SR420561N

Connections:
+5V: C1.1, R2.1, R3.2, R12.1, U1.16 (VCC); also elsewhere on the board
/Display/Cathode_1: Q1.1 (G), R13.1; also elsewhere on the board
/Display/Cathode_2: Q2.1 (G), R16.1; also elsewhere on the board
/Display/Cathode_3: Q3.1 (G), R17.1; also elsewhere on the board
/Display/Cathode_4: Q4.1 (G), R18.1; also elsewhere on the board
/Display/Encoder_Switch: R12.2, SW3.S1; also elsewhere on the board
/Display/LED_1: R14.1; also elsewhere on the board
/Display/LED_2: R15.1; also elsewhere on the board
/Display/RCLK: U1.12 (RCLK); also elsewhere on the board
/Display/SEG_A: R6.1, U1.2 (QC)
/Display/SEG_B: R4.1, U1.15 (QA)
/Display/SEG_C: R8.1, U1.4 (QE)
/Display/SEG_D: R10.1, U1.6 (QG)
/Display/SEG_DP: R9.1, U1.5 (QF)
/Display/SEG_E: R11.1, U1.7 (QH)
/Display/SEG_F: R5.1, U1.1 (QB)
/Display/SEG_G: R7.1, U1.3 (QD)
/Display/SER: U1.14 (SER); also elsewhere on the board
/Display/SRCLK: U1.11 (SRCLK); also elsewhere on the board
/Display/~OE: U1.13 (~OE); also elsewhere on the board
/Display/~SRCLR: U1.10 (~SRCLR); also elsewhere on the board
/Encoder_A: R2.2, SW3.A; also elsewhere on the board
/Encoder_B: R3.1, SW3.B; also elsewhere on the board
GND: C1.2, D1.1 (K), D2.1 (K), Q1.2 (S), Q2.2 (S), Q3.2 (S), Q4.2 (S), R13.2, R16.2, R17.2, R18.2, SW3.C, SW3.S2, U1.8 (GND); also elsewhere on the board
unnamed: D1.2 (A), R14.2
unnamed: D2.2 (A), R15.2
unnamed: Q1.3 (D), U2.6 (CC4)
unnamed: Q2.3 (D), U2.8 (CC3)
unnamed: Q3.3 (D), U2.9 (CC2)
unnamed: Q4.3 (D), U2.12 (CC1)
unnamed: R4.2, U2.7 (b)
unnamed: R5.2, U2.10 (f)
unnamed: R6.2, U2.11 (a)
unnamed: R7.2, U2.5 (g)
unnamed: R8.2, U2.4 (c)
unnamed: R9.2, U2.3 (DPX)
unnamed: R10.2, U2.2 (d)
unnamed: R11.2, U2.1 (e)

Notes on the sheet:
Pinbelegung und Nummerierung aus Routinggründen nicht geordnet

Board: 2 copper layers, 43 parts (6 on the bottom side), 48 nets, no tracks yet.

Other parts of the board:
SW1#2: Reset Button; WJ15EDGRC-3.81-2P

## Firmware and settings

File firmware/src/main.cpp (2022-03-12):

#include <Arduino.h>
#include <AccelStepper.h>

#include "display.hpp"
#include "config.hpp"



// Pins for the quadrature encoder and encoder switch.
#define ENC_SW 2
#define ENC_A A3
#define ENC_B A4

// Pins for the PCB-mounted LEDs. Not applicable to production units.
#define PCBLED1 3
#define PCBLED2 4


// Maximum counter value. Values above 9999 and below 1 are not supported.
#define MAX_COUNTER 9999

// Pins for the stepper driver. ENA can be left unconnected.
#define STEP A0
#define DIR A1
#define ENA A2



AccelStepper stepper(AccelStepper::DRIVER, STEP, DIR);

const uint64_t pulsesPerRev = STEPS_PER_REV * INDEXING_HEAD_GEAR_RATIO;
const long maxPulsesPerSec = (MAX_SPEED / 60) * STEPS_PER_REV;
const long maxAcceleration = (MAX_ACCEL / 60) * STEPS_PER_REV;

char previousEncoderA = LOW;
char previousEncoderB = LOW;
char previousEncoderSwitch = HIGH; // switch has pull up resistor, so the default value is HIGH

void setup() {
	pinMode(PCBLED1, OUTPUT);
	pinMode(PCBLED2, OUTPUT);

	pinMode(STEP, OUTPUT);
	pinMode(DIR, OUTPUT);
	// pinMode(ENA, OUTPUT); // not needed

	pinMode(ENC_SW, INPUT_PULLUP);
	pinMode(ENC_A, INPUT_PULLUP);
	pinMode(ENC_B, INPUT_PULLUP);

	setupDisplay();

	Serial.begin(9600);
	Serial.println("Starting");
	setDisplayText("HEL0");
	delay(1000);
	setDisplayText("    ");

	Serial.println("Configuring stepper driver pins");
	stepper.setEnablePin(ENA);
	stepper.setMaxSpeed(maxPulsesPerSec);
	stepper.setAcceleration(maxAcceleration);

	Serial.println("Configuring encoder");
	previousEncoderA = digitalRead(ENC_A);
	previousEncoderB = digitalRead(ENC_B);
	previousEncoderSwitch = digitalRead(ENC_SW);
}

int counter = 1;
uint64_t pulsesPerDivision = 0;

enum DeviceState {
	DIVISION_SELECT,
	WAIT_FOR_DRIVE,
	DRIVE
};

DeviceState deviceState = DIVISION_SELECT;

void divisionSelect(){
	// Read Encoder
	char encoderA = digitalRead(ENC_A);
	char encoderB = digitalRead(ENC_B);

	// Turn encoder state into counter value
	if(encoderA == HIGH && previousEncoderA == LOW) {
		if(encoderB == HIGH) {
			counter--;
		} else {
			counter++;
		}
	} else if(encoderA == LOW && previousEncoderA == HIGH) {
		if(encoderB == HIGH) {
			counter++;
		} else {
			counter--;
		}
	}

	previousEncoderA = encoderA;
	previousEncoderB = encoderB;

	// Limit counter value to range(0, MAX_COUNTER)
	counter = min(MAX_COUNTER, max(1, counter));
	
	// Display counter value on display
	setDisplayNumber(counter);

	// Wait for encoder switch to be pushed to confirm counter value and go to WAIT_FOR_DRIVE state
	if(digitalRead(ENC_SW) == LOW && previousEncoderSwitch == HIGH) {
		setDisplayText(" Loc");
		delay(1000);
		setDisplayText("    ");
		setDisplayNumber(counter);
		pulsesPerDivision = pulsesPerRev / counter;
		deviceState = WAIT_FOR_DRIVE;
		previousEncoderSwitch = LOW;
	}
}

void waitForDrive(){
	// Wait for button push
	char currentEncoderSwitch = digitalRead(ENC_SW);

	// If rotary encoder switch is pushed, go to DRIVE state and drive to target position
	if(currentEncoderSwitch == LOW) {
		deviceState = DRIVE;
		delay(10);
		Serial.print("Schritte: ");
		Serial.println((long)pulsesPerDivision);
		Serial.print("MSB: ");
		Serial.println((long)(pulsesPerDivision >> 32));
		digitalWrite(PCBLED1, HIGH);
		stepper.move(pulsesPerDivision);
	}
	previousEncoderSwitch = currentEncoderSwitch;
}

void drive(){
	// send pulses to led/driver
	stepper.run();

	if(stepper.currentPosition() == stepper.targetPosition()) {
		deviceState = WAIT_FOR_DRIVE;
		digitalWrite(PCBLED1, LOW);
		Serial.println("Position erreicht.");
	}
}

void loop() {
	// Main state machine
	switch (deviceState)
	{
	case DIVISION_SELECT:
		divisionSelect();
		break;
	case WAIT_FOR_DRIVE:
		waitForDrive();
		break;
	case DRIVE:
		drive();
		break;
	
	default:
		break;
	}
}

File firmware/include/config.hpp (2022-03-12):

#pragma once

// The gear reduction of the indexing head.
// Keep the "L" after the number and only use integer numbers
#define INDEXING_HEAD_GEAR_RATIO 90L

// The microstep setting of the stepper driver.
// Keep the "L" after the number and only use integer numbers
#define STEPS_PER_REV 400L




// ATTENTION!
// You probably don't need to change the following settings,
// if you do, make sure your motor still has enough torque
// and doesn't stall!

// Maximum Motor RPM
#define MAX_SPEED 90

// Max RPM/s acceleration
#define MAX_ACCEL 90
